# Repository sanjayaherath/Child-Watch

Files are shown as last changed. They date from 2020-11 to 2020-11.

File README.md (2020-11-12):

# Child-Watch

## Introduction ##

This project was developed for EE356-Electronic Product Design and Manufacture Project. A market ready prototype of a child watch was developed.

**Group Members:** [Sanjaya Herath](https://sanjayaherath.github.io/), [Yasiru Ranasinghe](https://www.researchgate.net/profile/Don_Yasiru_Ranasinghe), and [Anupamali Willamuna](https://www.linkedin.com/in/anupamali-willamuna-0743a11a4/?originalSubdomain=lk).

**Supervised by:** [Dr. Janaka Wijayakulasooriya](http://eng.pdn.ac.lk/deee/staff/academic/dr.j.wijayakulasooriya/profile.php), [Dr. Ruwan Ranaweera ](http://eng.pdn.ac.lk/pages/departmentHome/EE/otherpages/staff/rdbranaweera.html), and [Dr. Uditha Navaratne](http://eng.pdn.ac.lk/deee/staff/academic/mr.us.navaratne/profile.php)

## Project Overview ##

The firmware was developed using arduino and PCBs were designed using Eagle CAD. The main components of hardware were arduino pro mini, OLED display, and sim800l.
The child watch includes features such as send and receive a specific number of messages, digital clock, stop watch and recieve notifications through vibrations.

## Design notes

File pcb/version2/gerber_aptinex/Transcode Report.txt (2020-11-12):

   ---- Transcoding 'C:\Users\Ghost\Desktop\project\pcb\version2\gerber_aptinex\version3.GBL' ----   Thu Jan 10 21:57:25 2019

D13   --> D100
-----------------------------------------------------------------

   ---- Transcoding 'C:\Users\Ghost\Desktop\project\pcb\version2\gerber_aptinex\version3.GBS' ----   Thu Jan 10 21:57:25 2019

D11   --> D101
D12   --> D102
D13   --> D103
D14   --> D104
-----------------------------------------------------------------

   ---- Transcoding 'C:\Users\Ghost\Desktop\project\pcb\version2\gerber_aptinex\version3.GTL' ----   Thu Jan 10 22:00:45 2019

D12   --> D105
D13   --> D106
D14   --> D107
D15   --> D108
-----------------------------------------------------------------

   ---- Transcoding 'C:\Users\Ghost\Desktop\project\pcb\version2\gerber_aptinex\version3.GTO' ----   Thu Jan 10 22:01:16 2019

D11   --> D109
D12   --> D110
D13   --> D111
D14   --> D112
D15   --> D113
D16   --> D114
D17   --> D115
-----------------------------------------------------------------

   ---- Transcoding 'C:\Users\Ghost\Desktop\project\pcb\version2\gerber_aptinex\version3.GTP' ----   Thu Jan 10 22:01:19 2019

D11   --> D116
D12   --> D117
D13   --> D118
D14   --> D119
D15   --> D120
D16   --> D121
D17   --> D122
D18   --> D123
-----------------------------------------------------------------

   ---- Transcoding 'C:\Users\Ghost\Desktop\project\pcb\version2\gerber_aptinex\version3.GTS' ----   Thu Jan 10 22:01:19 2019

D11   --> D124
D12   --> D125
D13   --> D126
D14   --> D127
D15   --> D128
D16   --> D129
D17   --> D130
D18   --> D131
D19   --> D132
D20   --> D133
D21   --> D134
D22   --> D135
-----------------------------------------------------------------

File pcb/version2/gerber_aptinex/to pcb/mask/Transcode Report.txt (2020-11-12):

   ---- Transcoding 'C:\Users\Ghost\Desktop\project\pcb\version2\gerber_aptinex\to pcb\mask\version3.GBS' ----   Thu Jan 10 22:14:10 2019

D11   --> D104
D12   --> D105
D13   --> D106
D14   --> D107
-----------------------------------------------------------------

   ---- Transcoding 'C:\Users\Ghost\Desktop\project\pcb\version2\gerber_aptinex\to pcb\mask\version3.GTS' ----   Thu Jan 10 22:14:10 2019

D11   --> D108
D12   --> D109
D13   --> D110
D14   --> D111
D15   --> D112
D16   --> D113
D17   --> D114
D18   --> D115
D19   --> D116
D20   --> D117
D21   --> D118
D22   --> D119
-----------------------------------------------------------------

   ---- Transcoding 'C:\Users\Ghost\Desktop\project\pcb\version2\gerber_aptinex\to pcb\mask\version3.GBS' ----   Fri Jan 11 21:36:22 2019

D13   --> D100
D14   --> D101
-----------------------------------------------------------------

   ---- Transcoding 'C:\Users\Ghost\Desktop\project\pcb\version2\gerber_aptinex\to pcb\mask\version3.GBS' ----   Fri Jan 11 21:36:32 2019

D13   --> D102
D14   --> D103
-----------------------------------------------------------------

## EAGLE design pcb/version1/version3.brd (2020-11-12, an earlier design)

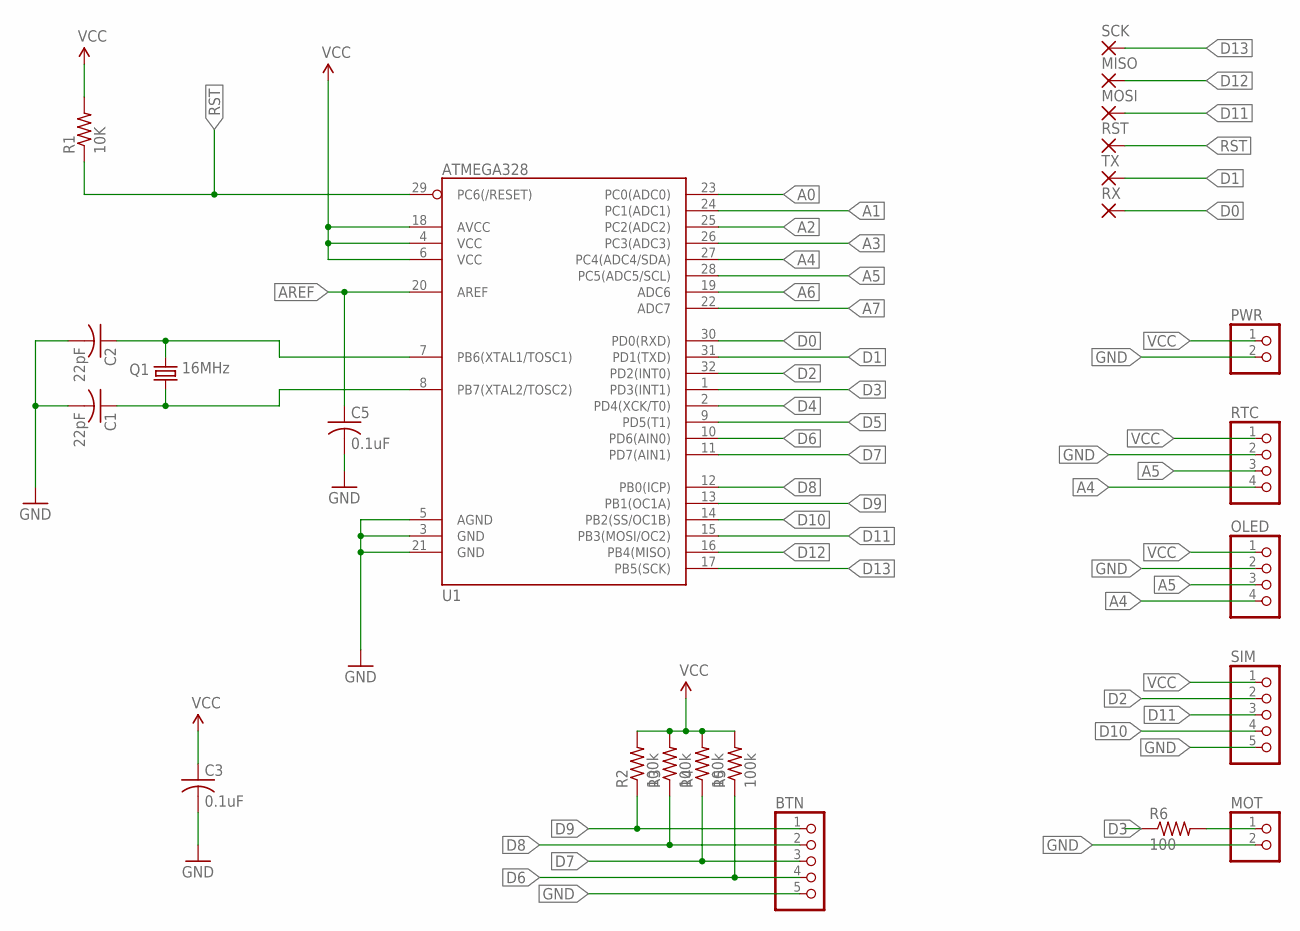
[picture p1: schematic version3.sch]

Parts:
BTN: PINHD-1X5; 1X05
C1, C2: 22pF; C1206
C3, C5: 0.1uF; C0805
MISO: SMD2; SMD1,27-2,54
MOSI: SMD2; SMD1,27-2,54
MOT: PINHD-1X2; 1X02
OLED: PINHD-1X4; 1X04
PWR: PINHD-1X2; 1X02
Q1: 16MHz; TC26V
R1: 10K; R1206
R2, R3, R4, R5: 100k; R1206
R6: 100; R1206
RST: SMD2; SMD1,27-2,54
RTC: PINHD-1X4; 1X04
RX: SMD2; SMD1,27-2,54
SCK: SMD2; SMD1,27-2,54
SIM: PINHD-1X5; 1X05
TX: SMD2; SMD1,27-2,54
U1: ATMEGA328; TQFP32-08

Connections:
A0: U1.23 (PC0(ADC0))
A1: U1.24 (PC1(ADC1))
A2: U1.25 (PC2(ADC2))
A3: U1.26 (PC3(ADC3))
A4: OLED.4, RTC.4, U1.27 (PC4(ADC4/SDA))
A5: OLED.3, RTC.3, U1.28 (PC5(ADC5/SCL))
A6: U1.19 (ADC6)
A7: U1.22 (ADC7)
AREF: C5.1, U1.20 (AREF)
D0: RX.1, U1.30 (PD0(RXD))
D1: TX.1, U1.31 (PD1(TXD))
D2: SIM.2, U1.32 (PD2(INT0))
D3: R6.1, U1.1 (PD3(INT1))
D4: U1.2 (PD4(XCK/T0))
D5: U1.9 (PD5(T1))
D6: BTN.4, R5.1, U1.10 (PD6(AIN0))
D7: BTN.3, R4.1, U1.11 (PD7(AIN1))
D8: BTN.2, R3.1, U1.12 (PB0(ICP))
D9: BTN.1, R2.1, U1.13 (PB1(OC1A))
D10: SIM.4, U1.14 (PB2(SS/OC1B))
D11: MOSI.1, SIM.3, U1.15 (PB3(MOSI/OC2))
D12: MISO.1, U1.16 (PB4(MISO))
D13: SCK.1, U1.17 (PB5(SCK))
GND: BTN.5, C1.2, C2.2, C3.2, C5.2, MOT.2, OLED.2, PWR.2, RTC.2, SIM.5, U1.3 (GND), U1.5 (AGND), U1.21 (GND)
unnamed: MOT.1, R6.2
unnamed: C2.1, Q1.2, U1.7 (PB6(XTAL1/TOSC1))
unnamed: C1.1, Q1.1, U1.8 (PB7(XTAL2/TOSC2))
RST: R1.1, RST.1, U1.29 (PC6(/RESET))
VCC: C3.1, OLED.1, PWR.1, R1.2, R2.2, R3.2, R4.2, R5.2, RTC.1, SIM.1, U1.4 (VCC), U1.6 (VCC), U1.18 (AVCC)

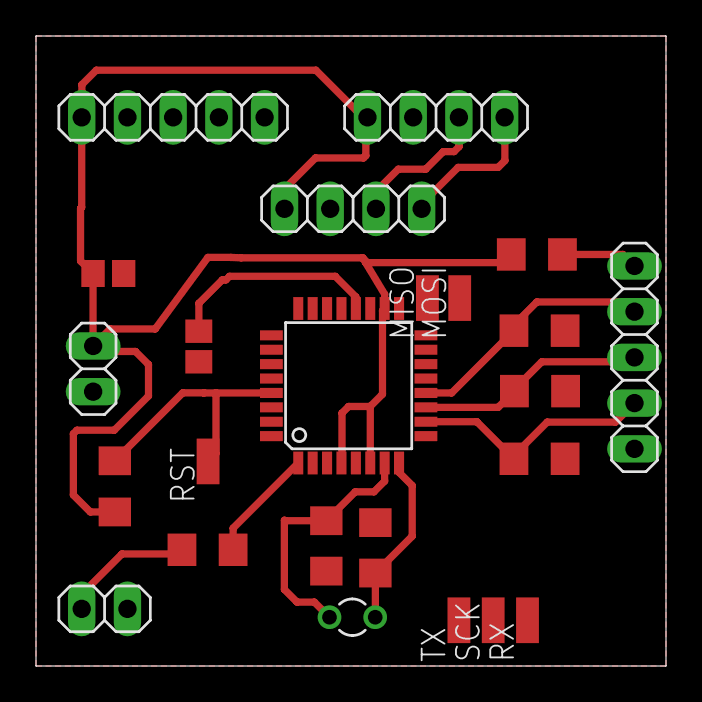
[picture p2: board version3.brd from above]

Board: 2 copper layers, 35.0 x 35.0 mm, 24 parts (0 on the bottom side), 21 nets.

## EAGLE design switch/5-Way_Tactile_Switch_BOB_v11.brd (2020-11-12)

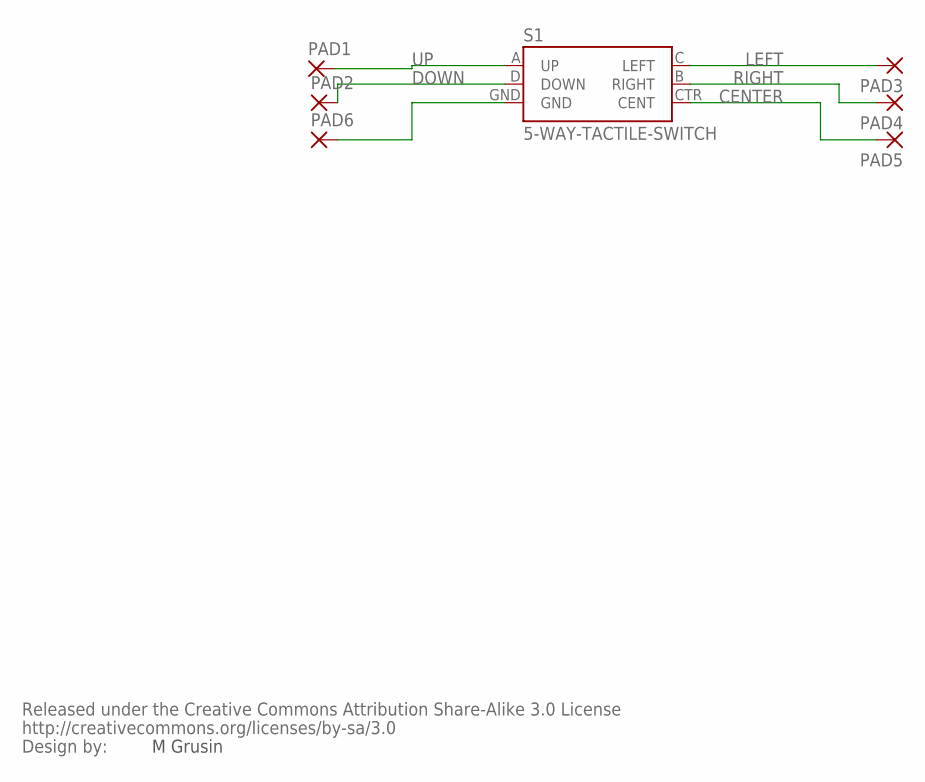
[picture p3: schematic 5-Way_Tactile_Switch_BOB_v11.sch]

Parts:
PAD1, PAD2, PAD3, PAD4, PAD5, PAD6: SMD2; SMD1,27-2,54
S1: 5-WAY-TACTILE-SWITCH; JOYSTICK_MINI
U$2: CREATIVE_COMMONS

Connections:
CENTER: PAD5.1, S1.CTR (CENT)
DOWN: PAD2.1, S1.D (DOWN)
GND: PAD6.1, S1.GND
LEFT: PAD3.1, S1.C (LEFT)
RIGHT: PAD4.1, S1.B (RIGHT)
UP: PAD1.1, S1.A (UP)

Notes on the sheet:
M Grusin

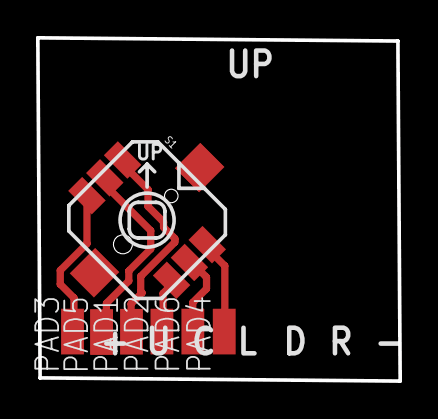
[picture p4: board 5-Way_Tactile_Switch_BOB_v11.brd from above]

Board: 2 copper layers, 20.1 x 19.1 mm, 8 parts (0 on the bottom side), 6 nets.

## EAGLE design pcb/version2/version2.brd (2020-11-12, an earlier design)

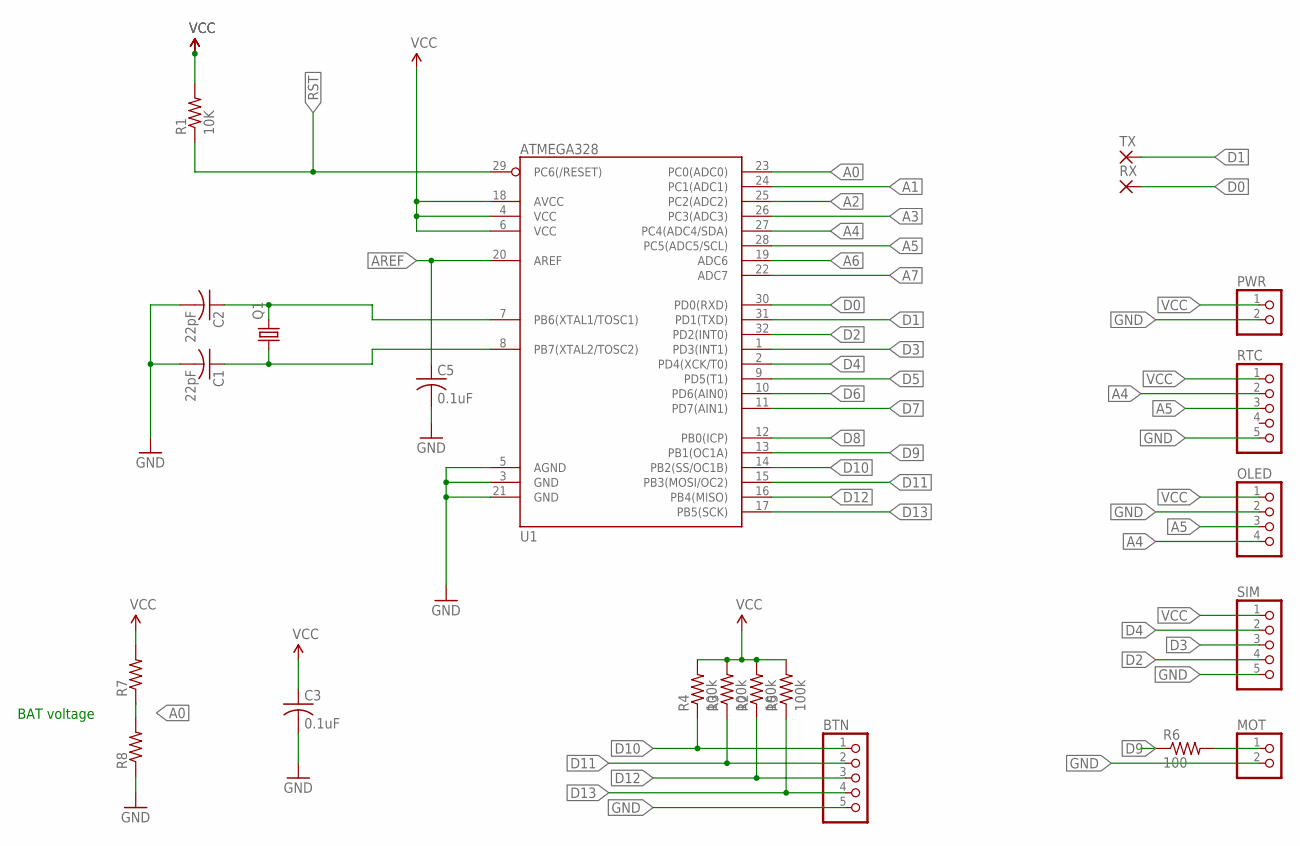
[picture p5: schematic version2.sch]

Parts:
BTN: PINHD-1X5; 1X05
C1, C2: 22pF; C1206
C3, C5: 0.1uF; C0805
MOT: PINHD-1X2; 1X02
OLED: PINHD-1X4; 1X04
PWR: PINHD-1X2; 1X02
Q1: CRYSTALHC18U-V; HC18U-V
R1: 10K; R0805
R2, R3, R4, R5: 100k; R0805
R6: 100; R0805
R7, R8: R-US_R0805; R0805
RTC: PINHD-1X5; 1X05
RX: SMD2; SMD1,27-2,54
SIM: PINHD-1X5; 1X05
TX: SMD2; SMD1,27-2,54
U1: ATMEGA328; TQFP32-08

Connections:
A0: R7.1, R8.2, U1.23 (PC0(ADC0))
A1: U1.24 (PC1(ADC1))
A2: U1.25 (PC2(ADC2))
A3: U1.26 (PC3(ADC3))
A4: OLED.4, RTC.2, U1.27 (PC4(ADC4/SDA))
A5: OLED.3, RTC.3, U1.28 (PC5(ADC5/SCL))
A6: U1.19 (ADC6)
A7: U1.22 (ADC7)
AREF: C5.1, U1.20 (AREF)
D0: RX.1, U1.30 (PD0(RXD))
D1: TX.1, U1.31 (PD1(TXD))
D2: SIM.4, U1.32 (PD2(INT0))
D3: SIM.3, U1.1 (PD3(INT1))
D4: SIM.2, U1.2 (PD4(XCK/T0))
D5: U1.9 (PD5(T1))
D6: U1.10 (PD6(AIN0))
D7: U1.11 (PD7(AIN1))
D8: U1.12 (PB0(ICP))
D9: R6.1, U1.13 (PB1(OC1A))
D10: BTN.1, R4.1, U1.14 (PB2(SS/OC1B))
D11: BTN.2, R3.1, U1.15 (PB3(MOSI/OC2))
D12: BTN.3, R2.1, U1.16 (PB4(MISO))
D13: BTN.4, R5.1, U1.17 (PB5(SCK))
GND: BTN.5, C1.2, C2.2, C3.2, C5.2, MOT.2, OLED.2, PWR.2, R8.1, RTC.5, SIM.5, U1.3 (GND), U1.5 (AGND), U1.21 (GND)
unnamed: MOT.1, R6.2
unnamed: C2.1, Q1.2, U1.7 (PB6(XTAL1/TOSC1))
unnamed: C1.1, Q1.1, U1.8 (PB7(XTAL2/TOSC2))
RST: R1.1, U1.29 (PC6(/RESET))
VCC: C3.1, OLED.1, PWR.1, R1.2, R2.2, R3.2, R4.2, R5.2, R7.2, RTC.1, SIM.1, U1.4 (VCC), U1.6 (VCC), U1.18 (AVCC)

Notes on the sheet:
BAT voltage

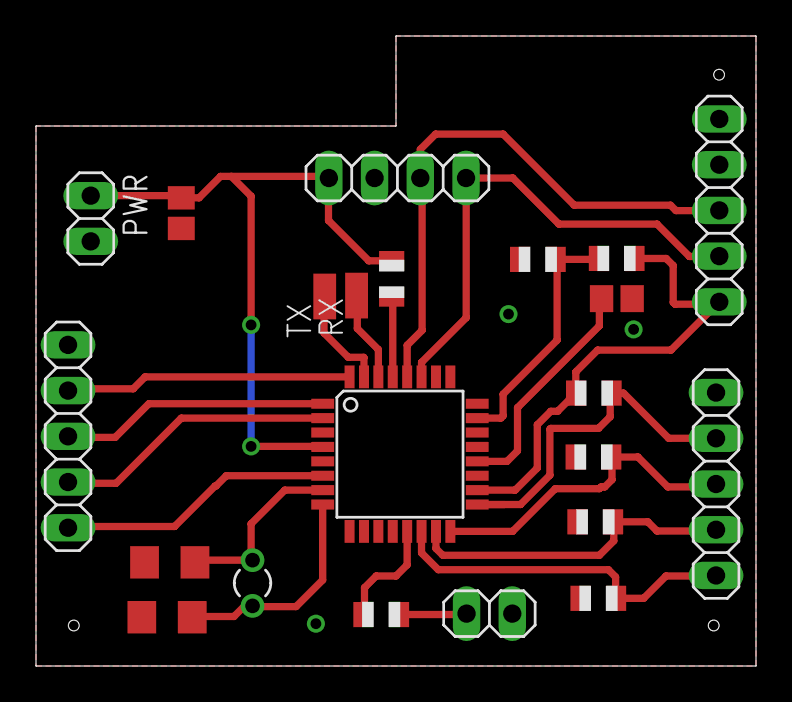
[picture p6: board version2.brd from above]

Board: 2 copper layers, 40.0 x 35.0 mm, 22 parts (0 on the bottom side), 20 nets.

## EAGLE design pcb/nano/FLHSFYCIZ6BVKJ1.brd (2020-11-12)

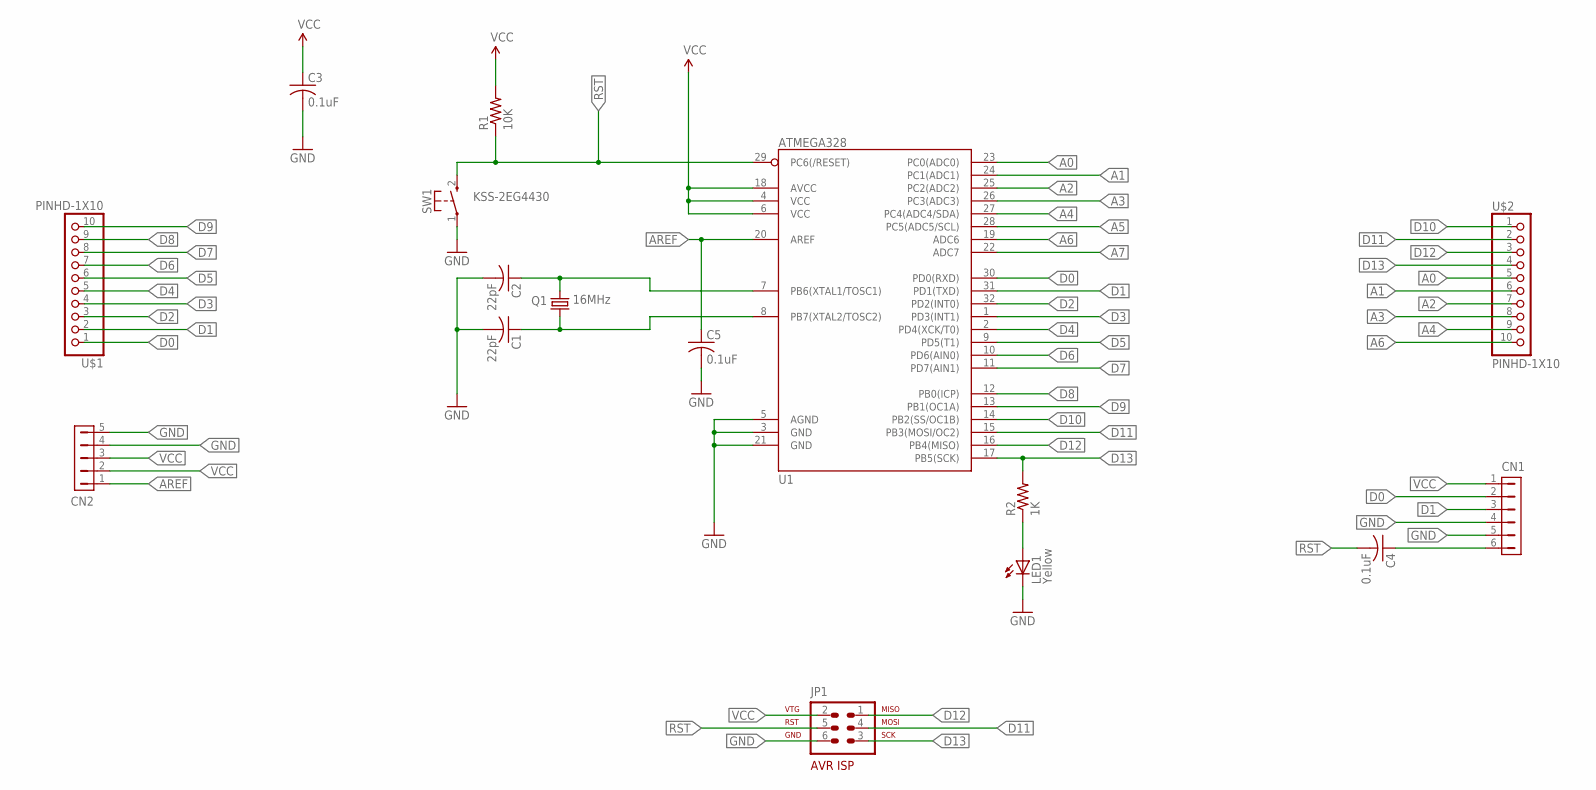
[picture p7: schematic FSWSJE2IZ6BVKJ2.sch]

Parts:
C1, C2: 22pF; C1206
C3, C4, C5: 0.1uF; C0805
CN1: HDR-1X6-SIP-100; SIP-100-6V
CN2: HDR-1X5-SIP-100; SIP-100-5V
JP1: AVR-ISP-6
LED1: Yellow; CHIP-LED0805
Q1: 16MHz; HC49/S
R1: 10K; R1206
R2: 1K; R1206
SW1: KSS-2EG4430
U1: ATMEGA328; TQFP32-08
U$1, U$2: PINHD-1X10; 1X10-BIG

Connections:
A0: U1.23 (PC0(ADC0)), U$2.5
A1: U1.24 (PC1(ADC1)), U$2.6
A2: U1.25 (PC2(ADC2)), U$2.7
A3: U1.26 (PC3(ADC3)), U$2.8
A4: U1.27 (PC4(ADC4/SDA)), U$2.9
A5: U1.28 (PC5(ADC5/SCL))
A6: U1.19 (ADC6), U$2.10
A7: U1.22 (ADC7)
AREF: C5.1, CN2.1, U1.20 (AREF)
D0: CN1.2, U1.30 (PD0(RXD)), U$1.1
D1: CN1.3, U1.31 (PD1(TXD)), U$1.2
D2: U1.32 (PD2(INT0)), U$1.3
D3: U1.1 (PD3(INT1)), U$1.4
D4: U1.2 (PD4(XCK/T0)), U$1.5
D5: U1.9 (PD5(T1)), U$1.6
D6: U1.10 (PD6(AIN0)), U$1.7
D7: U1.11 (PD7(AIN1)), U$1.8
D8: U1.12 (PB0(ICP)), U$1.9
D9: U1.13 (PB1(OC1A)), U$1.10
D10: U1.14 (PB2(SS/OC1B)), U$2.1
D11: JP1.4, U1.15 (PB3(MOSI/OC2)), U$2.2
D12: JP1.1, U1.16 (PB4(MISO)), U$2.3
D13: JP1.3, R2.2, U1.17 (PB5(SCK)), U$2.4
GND: C1.2, C2.2, C3.2, C5.2, CN1.4, CN1.5, CN2.4, CN2.5, JP1.6, LED1.C, SW1.1, U1.3 (GND), U1.5 (AGND), U1.21 (GND)
unnamed: C4.1, CN1.6
unnamed: C2.1, Q1.2, U1.7 (PB6(XTAL1/TOSC1))
unnamed: C1.1, Q1.1, U1.8 (PB7(XTAL2/TOSC2))
unnamed: LED1.A, R2.1
RST: C4.2, JP1.5, R1.1, SW1.2 (S), U1.29 (PC6(/RESET))
VCC: C3.1, CN1.1, CN2.2, CN2.3, JP1.2, R1.2, U1.4 (VCC), U1.6 (VCC), U1.18 (AVCC)

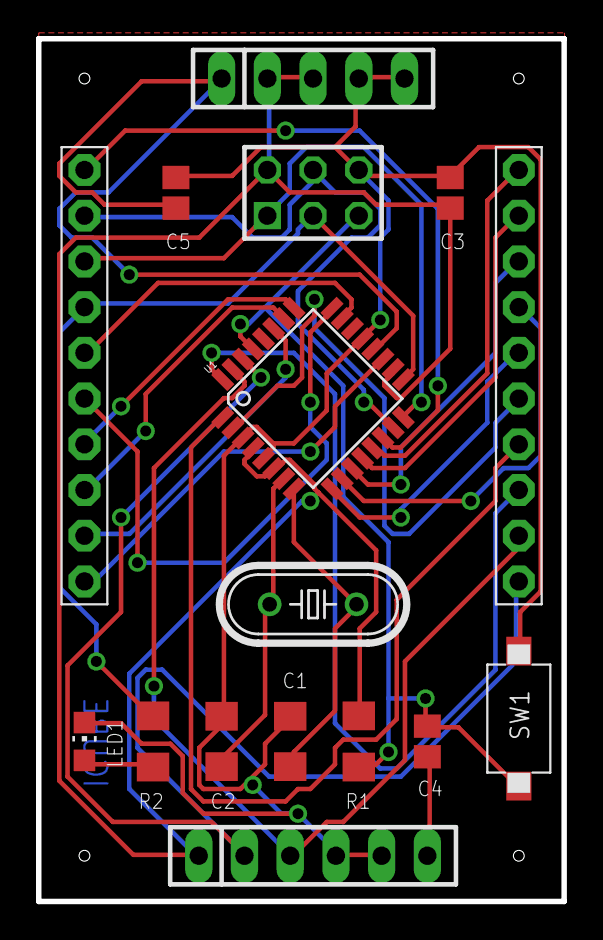
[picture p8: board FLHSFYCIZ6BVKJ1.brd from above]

Board: 2 copper layers, 29.2 x 47.9 mm, 16 parts (0 on the bottom side), 28 nets.

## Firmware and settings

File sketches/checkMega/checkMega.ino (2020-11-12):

#include <Wire.h>
#include <Adafruit_SSD1306.h>
#include "RTClib.h"
#include <Sim800l.h>
#include <SoftwareSerial.h>
#include <EEPROM.h>

RTC_DS3231 rtc;
#define OLED_RESET 4
Adafruit_SSD1306 display(OLED_RESET);

// Variable assignment
char daysOfTheWeek[7][12] = {"SUN", "MON", "TUE", "WED", "THU", "FRI", "SAT"};
char optionKey = 'M', commandKey = '0', preferenceKey;
// Variables for button press
char mode[4] = {'M', 'C', 'P'}, buttonKeyArray [4] = {'8', '5', '2', '4'};
int modeIndex = 0, centerPin = 7, upPin = 9, leftPin = 6, rightPin = 8;
long pressedTime = 0;
// Variables for watch quantities
int hourHand, minuteHand, secondHand;
int preHour, preMinute, preSecond;
int durationOff = 100;
// Variable for stopwatch quantites
int stopHour = 0, stopMinute = 0, stopSecond = 0;
int saveHour = 0, saveMinute = 0, saveSecond = 0, saveMilliSecond = 0;
int startHour, startMinute, startSecond;
int stopMilliSecond = 0, inProgress = 0;
int preStopMilliSecond, preStopSecond, preStopMinute;
int stopMinuteX = 0, stopSecondX = 54, stopMilliSecondX = 108, stopwatchY = 5;
int /*durationSW,*/ initiateStopwatch, loopDelayCount = 20;
// Variable for clock setting
int resetUnit, preChangeUnit = 0, modulusArray[] = {2100, 12, 31, 24, 60};;
// Variables for animation
int lineLength = 0, blackOn = 1;
// Cursor positions
// DateTimeX = {minuteX, hourX, dateX, monthX, yearX}
int DateTimeX[] = {70, 20, 30, 55, 80}, dotX = 56, slashX1 = 45, slashX2 = 70;
// DateTimeY = {timeY, timeY, dateY, dateY, dateY}
int DateTimeY[] = {12, 12, 2, 2, 2}, dotY = 12, slashY = 2;
// Variables for the GSM module
Sim800l Sim800l;  //to declare the library
String numberSms, textSms;
uint8_t index, msgIndex = 1;   // to indicate the message to read.
bool error;       // to store the error output
//bool match;       // to check whether numbers match
String number = "+94719688884";
int motPin = 3, checkSmsDelay = 1, checkSmsTimes = 3;
// Variables for the Pin enter window
int pinArray[4], pinIndex, disableMode = 0;
int pinCursorX[] = {25, 45, 65, 85}, pinCursorY = 12;
// Variables for the Pin/ Contact Info change window
int settingsMode, savedContacts[2][10], EntryX;
int contactCursorX[] = {10, 21, 32, 43, 54, 65, 76, 87, 98, 109}, contactCursorY = 15;
int blinkItCount = 0;
String Number1, Number2;
char contactInfo[13];
//int screenOff = 0;
//unsigned long screenOffTimer;

// Declaring methods
void mainWindowTimeAndDate();
void mainWindowAnime();
void runStopwatch();
void runClockSetting();

void displayColan();
void printHand();
void printDate();
void dotsTicking();
void printDateAndTime();
void drawHoriLine();
void showStopwatch();
void setResetUnitCursor();

void setup()   {

  //Serial.begin(9600);
  display.begin(SSD1306_SWITCHCAPVCC, 0x3C);
  DateTime now = rtc.now();
  printDateAndTime(now.day(), now.month(), daysOfTheWeek[now.dayOfTheWeek()]);

  //gsm
  Sim800l.begin(); // initializate the library.
  //Sim800l.reset();
  pinMode(motPin, OUTPUT);
  index = 1; // first position in the prefered memory storage.
  contactInfo[0] = '+', contactInfo[1] = '9', contactInfo[2] = '4', contactInfo[12] = '\0';
  for (int address = 5; address < 14; address++) {
    contactInfo[address - 2] = EEPROM.read(address) + '0';
  }
  Number1 = (String)(contactInfo);
  for (int address = 15; address < 24; address++) {
    contactInfo[address - 12] = EEPROM.read(address) + '0';
  }
  Number2 = (String)(contactInfo);
}

void loop() {

  //  Serial.println(Number1);
  //  Serial.println(Number2);
  commandKey = '0'; // reset command key to read only once

  DateTime now = rtc.now();
  checkButtonPress(); // Check any buttons are pressed


  // Run main window section
  if (optionKey == 'M') {
    mainWindowTimeAndDate();
    mainWindowAnime();
  }
  // Run setting section
  if (optionKey != 'C')resetUnit = 0;
  if (optionKey == 'C') {
    runClockSetting();
  }

  // Run pin enter section
  if (optionKey == 'P' && disableMode == 0) {
    display.setCursor(pinCursorX[pinIndex], pinCursorY);
    display.print(pinArray[pinIndex]);
    display.display();
    switch (commandKey) {
      case '2':
      case '8':
        changePinValue();
        break;
      case '4' :
        changeIndexOrCheckPin();
        break;
    }
  }

  //gsm


  if (lineLength % 33 == 0 && blackOn == 1) checkSmsDelay++;
  if ((checkSmsDelay % checkSmsTimes) == 0) {
    checkSmsDelay = 1;
    checkSms();
  }


  // Run pin / contact info change section
  if (disableMode == 1) {
    //Serial.println(EntryX);
    displayInfo();
    switch (commandKey) {
      case '4':
        increaseEntryX();
        break;
      case '2':
      case '8':
        changeEntryValue();
        break;
    }
  }
}

/////////////////////////////////////// MAIN METHODS /////////////////////////////////////////////
// Check for the pressed button
void checkButtonPress() {
  // Check for the pressed button
  for (int pinVal = 6; pinVal < 10; pinVal++) {
    if (digitalRead(pinVal) == LOW && (millis() - pressedTime) > 150) {
      // Get the corresponding keypad button
      pressedTime = millis();
      commandKey = buttonKeyArray[pinVal - 6];
      if (commandKey == '5' && disableMode == 0) modeIndex = (++modeIndex) % 3;
      if (disableMode == 1 && commandKey == '5') {
        settingsMode = (++settingsMode) % 4;
        display.clearDisplay(); EntryX = 0;
      }
    }
  }

/*
  if (commandKey != '0' && screenOff == 0) {
    screenOffTimer = millis();
  }

  if (millis() - screenOffTimer > 60000 && screenOff != 1) {
    display.clearDisplay();
    display.display();
    screenOff = 1;
  }
  else if(commandKey != '0' && screenOff == 1 ){ 
    screenOff = 0;    
    screenOffTimer = millis();
    modeIndex = 0;
    optionKey = 'C';
 }
*/
  preferenceKey = mode[modeIndex];
  // Current window is the main window
  if (preferenceKey == 'M' && optionKey != 'M') {
    //durationSW = 52;
    optionKey = 'M';
    DateTime now = rtc.now();
    printDateAndTime(now.day(), now.month(), daysOfTheWeek[now.dayOfTheWeek()]);
    lineLength = 0; blackOn = 1;
  }
  // Current window is the settings window
  if (preferenceKey == 'C' && optionKey != 'C') {
    display.clearDisplay();
    //durationSW = 50;
    optionKey = 'C';
  }
  // Current window is the enter pin window
  if (preferenceKey == 'P' && optionKey != 'P') {
    //durationSW = 50;
    optionKey = 'P';
    displayEnterPin();
    pinIndex = 0;
    for (int index = 0; index < 4; index++) {
      pinArray[index] = 0;
    }
  }
}

// Main window of the clock
void mainWindowTimeAndDate() {
//  if(screenOff == 1) return;
  displayColan(':');
  display.display();
  DateTime now = rtc.now();
  preSecond = secondHand;
  secondHand = now.second();
  if (secondHand == 0) {
    preMinute = minuteHand;
    minuteHand = now.minute();
    // Display the change in minutes
    printHand(preMinute, minuteHand, DateTimeX[0], DateTimeY[0], 2);

    // Trigger hour change
    if (preMinute > minuteHand) {
      preHour = hourHand;
      hourHand = now.hour();
      // Display the change in hours
      printHand(preHour, hourHand, DateTimeX[1], DateTimeY[1], 2);

      // Trigger date change
      if (preHour > hourHand) {
        printDateAndTime(now.day(), now.month(), daysOfTheWeek[now.dayOfTheWeek()]);
      }
    }
  }
  if (preSecond != secondHand) {
    display.setCursor(dotX, dotY);
    display.setTextColor(BLACK);
    displayColan(':');
    display.display();
    delay(durationOff);
    display.setTextColor(WHITE);
  }
}

// Main window animation
void mainWindowAnime() {
  //  if (commandKey == '4') sendMessage();
  if (preSecond == secondHand) delay(durationOff);
  lineLength = lineLength % 33;
  if (lineLength == 0 && blackOn == 1)blackOn = 0;
  else if (lineLength == 0)blackOn = 1;
//  lineLength++;
//  if(screenOff == 1) return;
  drawHoriLine(lineLength++);
}

// Run clock setting window
void runClockSetting() {
  if (commandKey == '4') {
    resetUnit = ++resetUnit % 5;
  }
  setResetUnitCursor();
}

/////////////////////////////////////SUBORDINATE METHODS////////////////////////////////
// Print time quantites
void printHand(int preUnit, int timeUnit, int cursorX, int cursorY, int numDigit) {
  display.setCursor(cursorX, cursorY);
  display.setTextColor(BLACK);
  if (preUnit < 10 && numDigit == 2)display.print(0);
  display.print(preUnit);
  display.setCursor(cursorX, cursorY);
  display.setTextColor(WHITE);
  if (timeUnit < 10 && numDigit == 2)display.print(0);
  display.print(timeUnit);
}
// Print date quantites
void printDate(int timeUnit, int cursorX, int cursorY) {
  display.setCursor(cursorX, cursorY);
  display.setTextColor(WHITE);
  display.setTextSize(1);
  display.print(timeUnit);
  display.setTextSize(3);
}
//Display date/month DAY
void printDateAndTime(int dayInfo, int monthInfo, String dayName) {
  display.clearDisplay();
  display.setCursor(DateTimeX[2], DateTimeY[2]);
  display.setTextColor(WHITE);
  display.setTextSize(1);
  display.print(dayInfo);
  display.print(" / ");
  display.print(monthInfo);
  display.print("  ");
  display.print(dayName);
  display.setTextSize(3);
  DateTime now = rtc.now();
  hourHand = now.hour(); minuteHand = now.minute(); secondHand = now.second();
  printHand(0, hourHand, DateTimeX[1], DateTimeY[1], 2);
  printHand(0, minuteHand, DateTimeX[0], DateTimeY[0], 2);
}
// Display the animation
void drawHoriLine(int lineWidth) {
  int cursorX = 0;
  double width = (double)lineWidth ;
  width++;
  width = ceil((width / 8) * (width / 6));
  while (cursorX < width) {
    if (blackOn == 0) {
      display.drawPixel(cursorX, 31 - lineWidth, WHITE);
      display.drawPixel(127 - cursorX++, 31 - lineWidth, WHITE);
    }
    else {
      display.drawPixel(cursorX, 31 - lineWidth, BLACK);
      display.drawPixel(127 - cursorX++, 31 - lineWidth, BLACK);
    }
  }
//  if(screenOff == 1) display.clearDisplay();
}

// Set stopwatch screen and display
void showStopwatch() {
  display.setTextColor(WHITE);
  display.setTextSize(3);
  display.clearDisplay();
  // Display the minute in stopwatch
  printHand(0, preStopMinute, stopMinuteX, stopwatchY, 2);
  display.print(":");
  // Display the second in stopwatch
  printHand(0, preStopSecond, stopSecondX, stopwatchY, 2);
  display.print(":");
  // Display the milliscond in stopwatch
  printHand(0, preStopMilliSecond, stopMilliSecondX, stopwatchY, 1);
  display.display();
}

// Change clock settings
void setResetUnitCursor() {
  DateTime now = rtc.now();
  int currentSettings[] = {(int)now.year(), now.month(), now.day(), now.hour(), now.minute()};
  int changeIndex = 4 - resetUnit, changeUnit = currentSettings[changeIndex];
  int timeBound = modulusArray[changeIndex];
  if (preChangeUnit != changeUnit) {
    display.clearDisplay();
    preChangeUnit = changeUnit;
  }
  display.setTextSize(3); display.setTextColor(WHITE);
  displayColan(':'); displayColan('/'); display.display();

  if (resetUnit < 2) printHand(0, changeUnit, DateTimeX[resetUnit], DateTimeY[resetUnit], 2);
  else printDate(changeUnit, DateTimeX[resetUnit], DateTimeY[resetUnit]);
  display.display();
  if (commandKey == '2' || commandKey == '8') {
    changeUnit = changeUnit + (commandKey == '2') - (commandKey == '8');
    changeUnit = (timeBound + (changeUnit % timeBound)) % timeBound;
    switch (changeIndex) {
      case 0:
      case 1:
      case 2:
        changeUnit = timeBound * (changeUnit == 0) + changeUnit;
        break;
    }
    currentSettings[changeIndex] = changeUnit;
    rtc.adjust(DateTime(currentSettings[0], currentSettings[1], currentSettings[2], currentSettings[3], currentSettings[4], 0));
  }

  // Save parameters for the stopwatch
  if (commandKey == '2' || commandKey == '8') {
    saveHour = stopHour, saveMinute = preStopMinute, saveSecond = preStopSecond;
    saveMilliSecond = preStopMilliSecond;
    initiateStopwatch = 0;
  }
}
// Display colans
void displayColan(char sign) {
  switch (sign) {
    case ':':
      display.setCursor(dotX, dotY);
      display.print(':');
      break;
    case '/':
      display.setTextSize(1);
      display.setCursor(slashX1, slashY);
      display.print('/');
      display.setCursor(slashX2, slashY);
      display.print('/');
      display.setTextSize(3);
      break;
  }
}
// Display 'Enter Pin'
void displayEnterPin() {
  display.clearDisplay();
  display.setTextSize(1);
  display.setCursor(DateTimeX[2] - 6, DateTimeY[2]);
  display.print("**Enter Pin**");
  display.setTextSize(3);
}
// Entering the pin
void changePinValue() {
  int pinValue = pinArray[pinIndex];
  pinValue = pinValue + (commandKey == '2') - (commandKey == '8');
  pinArray[pinIndex] = (10 + pinValue) % 10;
  displayEnterPin();
}
// Change the digit of the 4-digit Pin and check for permission
void changeIndexOrCheckPin() {
  int misMatch = 0;
  if (++pinIndex > 3) {
    for (int address = 0; address < 4; address++) {
      if (EEPROM.read(address) != pinArray[address]) {
        optionKey = 'M';
        misMatch = 1;
      }
    }
    if (misMatch == 0) {
      disableMode = 1;
      display.clearDisplay();
      settingsMode = 0, EntryX = 0, commandKey = '0';
      loadValues();
    }
  }
  else {
    displayEnterPin();
  }
}
// Load values from the EEPROM to the program
void loadValues() {
  // Storing the contact information
  for (int infoRow = 0; infoRow < 2; infoRow++) {
    for (int infoCol = 0; infoCol < 10; infoCol++) {
      int address = 10 * (infoRow) + infoCol + 4;
      savedContacts[infoRow][infoCol] = EEPROM.read(address);
    }
  }
}
// Display information in settings window
void displayInfo() {
  switch (settingsMode) {
    case 0: // Display the pin number
      display.setTextSize(1);
      display.setCursor(DateTimeX[2] - 12, DateTimeY[2]);
      display.print("*Enter New Pin*");
      display.setTextSize(3);
      for (int index = 0; index < 4; index ++) {
        display.setCursor(pinCursorX[index], pinCursorY);
        display.print(pinArray[index]);
      }
      display.display();
      blinkItCount = (++blinkItCount) % 20;
      if (blinkItCount == 0)blinkIt(pinArray[EntryX], pinCursorX[EntryX], pinCursorY);
      break;
    case 1: // Display the contact info 1
      display.setTextSize(1);
      display.setCursor(DateTimeX[2] + 6, DateTimeY[2]);
      display.print("Contact 1");
      display.setTextSize(2);
      for (int index = 0; index < 10; index ++) {
        display.setCursor(contactCursorX[index], contactCursorY);
        display.print(savedContacts[0][index]);
      }
      display.display();
      blinkItCount = (++blinkItCount) % 20;
      if (blinkItCount == 0)blinkIt(savedContacts[0][EntryX], contactCursorX[EntryX], contactCursorY);
      display.setTextSize(3);
      break;
    case 2: // Display the contact info 2
      display.setTextSize(1);
      display.setCursor(DateTimeX[2] + 6, DateTimeY[2]);
      display.print("Contact 2");
      display.setTextSize(2);
      for (int index = 0; index < 10; index ++) {
        display.setCursor(contactCursorX[index], contactCursorY);
        display.print(savedContacts[1][index]);
      }
      display.display();
      blinkItCount = (++blinkItCount) % 20;
      if (blinkItCount == 0)blinkIt(savedContacts[1][EntryX], contactCursorX[EntryX], contactCursorY);
      display.setTextSize(3);
      break;
    case 3: // Display the save settings window
      display.setTextSize(1);
      display.setCursor(DateTimeX[2] - 6, DateTimeY[2]);
      display.print("Save settings?");
      //display.setCursor(DateTimeX[2] - 10, DateTimeY[2] + 14);
      display.setCursor(0, DateTimeY[2] + 10);
      display.print("Move, Forward to save");
      //display.setCursor(DateTimeX[2] - 10, DateTimeY[2] + 24);
      display.setCursor(10, DateTimeY[2] + 20);
      display.print("Backward to cancel");
      display.display();
      break;
  }
}
// Blink the current variable digit
void blinkIt(int value, int cursorX, int cursorY) {
  display.setCursor(cursorX, cursorY);
  display.setTextColor(BLACK);
  display.print(value);
  display.display();
  delay(100);
  display.setTextColor(WHITE);
}
// Change the value of the current variable digit
void changeEntryValue() {
  switch (settingsMode) {
    case 0:
      pinArray[EntryX] = pinArray[EntryX] + (commandKey == '2') - (commandKey == '8');
      pinArray[EntryX] = (10 + pinArray[EntryX] % 10) % 10;
      display.clearDisplay();
      break;
    case 1:
      savedContacts[0][EntryX] = savedContacts[0][EntryX] + (commandKey == '2') - (commandKey == '8');
      savedContacts[0][EntryX] = (10 + savedContacts[0][EntryX] % 10) % 10;
      display.clearDisplay();
      break;
    case 2:
      savedContacts[1][EntryX] = savedContacts[1][EntryX] + (commandKey == '2') - (commandKey == '8');
      savedContacts[1][EntryX] = (10 + savedContacts[1][EntryX] % 10) % 10;
      display.clearDisplay();
      break;
    case 3:
      switch (commandKey) {
        case '2':
          // Save the new pin and return to main window
          for (int addressI = 0; addressI < 2; addressI++ ) {
            for (int addressJ = 0; addressJ < 10; addressJ++ ) {
              int address = 10 * addressI + addressJ + 4;
              EEPROM.write(address, savedContacts[addressI][addressJ]);
              if (address > 4 && address < 14) {
                contactInfo[address - 2] = savedContacts[addressI][addressJ] + '0';
                if (address == 13) {
                  //contactInfo[12] = '\0';
                  Number1 = (String)(contactInfo);
                }
              }
              else if (address > 14 && address < 24) {
                contactInfo[address - 12] = savedContacts[addressI][addressJ] + '0';
                if (address == 23) {
                  //contactInfo[12] = '\0';
                  Number2 = (String)(contactInfo);
                }
              }
            }
          }
          for (int address; address < 4; address++) {
            EEPROM.write(address, pinArray[address]);
          }
          for (int index = 0; index < 4; index++) {
            pinArray[index] = 0;
          }
          disableMode = 0;
          display.clearDisplay();
          display.setCursor(30, 10);
          display.setTextSize(2);
          display.print("Saved!");
          display.display();
          delay(1000);
          modeIndex = (++modeIndex) % 3;
          break;
        case '8':
          // Discard changes and return to main window
          disableMode = 0;
          display.clearDisplay();
          display.display();
          modeIndex = (++modeIndex) % 3;
          break;
      }
  }
}
// Change the index of the variable digit
void increaseEntryX() {
  switch (settingsMode) {
    case 0:
      EntryX = (++EntryX) % 4;
      break;
    case 1:
    case 2:
      EntryX = (++EntryX) % 10;
      break;
  }
}

// GSM METHODS //////////////////////////////

void checkSms() {
  delay(100);
  numberSms = Sim800l.getNumberSms(msgIndex);
  delay(100);
  Serial.print(numberSms + "\t");
  Serial.println(msgIndex);
  delay(1000);

  if (numberSms.equals(Number2) || numberSms.equals(Number2)) {
    // Serial.println("match");
    displayMesRec();
    playSmsAlarm();
    delay(5000);
    //sendMessage();
  }

  if (numberSms.length() > 10) {
    msgIndex++;
  }
  if (msgIndex > 1) {
    msgIndex = 1;
    Sim800l.delAllSms();
  }
}

void displayMesRec() {
  display.clearDisplay();
  display.setCursor(20, 15);
  display.setTextSize(1);
  display.print("Message Received");
  display.display();
  display.setTextSize(3);
  display.clearDisplay();
  DateTime now = rtc.now();
  printDateAndTime(now.day(), now.month(), daysOfTheWeek[now.dayOfTheWeek()]);
}

void sendMessage() {          // send sms to contacts
  char* sendsmstext = "match";
  error = Sim800l.sendSms(number, sendsmstext);
  if (error) {
    digitalWrite(motPin, HIGH);
    delay(800);
    digitalWrite(motPin, LOW);
  }


}

void playSmsAlarm() {         //sms received notification motor
  for (int i = 0; i < 5; i++) {
    digitalWrite(motPin, HIGH);
    delay(400);
    digitalWrite(motPin, LOW);
    delay(200);
    digitalWrite(motPin, HIGH);
    delay(400);
    digitalWrite(motPin, LOW);
    delay(1000);
  }
}

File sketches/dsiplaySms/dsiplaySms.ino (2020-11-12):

//#include <SPI.h>
#include <Wire.h>
//#include <Adafruit_GFX.h>
#include <Adafruit_SSD1306.h>
#include "RTClib.h"
#include <Sim800l.h>
#include <SoftwareSerial.h> //is necesary for the library!! 
#include "U8glib.h"

RTC_DS3231 rtc;
#define OLED_RESET 4
Adafruit_SSD1306 display(OLED_RESET);

// Variable assignment
char daysOfTheWeek[7][12] = {"SUN", "MON", "TUE", "WED", "THU", "FRI", "SAT"};
char optionKey = 'M', commandKey = '0';
char preferenceKey;
// Variables for button press
char mode[5] = {'M', 'S', 'C', 'P'};
int modeIndex = 0, centerPin = 7, upPin = 9, leftPin = 6, rightPin = 8;
long pressedTime = 0;
// Variables for time quantities 
int hourHand, minuteHand, secondHand;
int preHour, preMinute, preSecond;
// Variable for stopwatch quantites
int stopMinute = 0, stopSecond = 0, stopMilliSecond = 0, inProgress = 0, preUnit, resetSW = 0;
int stopMinuteX = 0, stopSecondX = 54, stopMilliSecondX = 108, stopwatchY = 5;
int durationSW, resetUnit, loopDelayCount = 20;
// Variables for animation
int lineLength = 0, blackOn = 1;
// Cursor positions
int hourX = 20, minuteX = 70, dotX = 54, timeY = 12;
int dateX = 30, dateY = 2,durationOff;
//gsm
Sim800l Sim800l;  //to declare the library
String numberSms;
uint8_t index;   // to indicate the message to read.
bool error;       // to store the error output
bool match;       // to check whether numbers match
String number ="+94719688884";
int LEDpin=5, checkSmsDelay = 1, checkSmsTimes = 10;

// Declaring methods
void mainWindowTimeAndDate();
void mainWindowAnime();
void runStopwatch();
void runClockSetting();

void displayColan();
void printHand();
void dotsTicking();
void printDateAndTime();
void drawHoriLine();
void reserStopwatch();
void setResetUnitCursor();

void setup()   {               
  Serial.begin(9600);
 // rtc.adjust(DateTime(2018, 11, 8, 10, 53, 00));
  // by default, we'll generate the high voltage from the 3.3v line internally! (neat!)
  display.begin(SSD1306_SWITCHCAPVCC, 0x3C);  // initialize with the I2C addr 0x3C (for the 128x32)
  DateTime now = rtc.now();
  printDateAndTime(now.day(),now.month(),daysOfTheWeek[now.dayOfTheWeek()]);
//gsm
  
  Sim800l.begin(); // initializate the library. 
  index=1; // first position in the prefered memory storage. 
  
}
int times = 0;
void loop(){
  // Set duration for pulsating 
  if(inProgress == 0)durationOff = 80;
  if(inProgress == 1)durationOff = 10;
  commandKey = '0';
  
  DateTime now = rtc.now();
  // Check button press
    checkButtonPress();
  /* 
  // Read from the serial 
  if(Serial.available()){
    preferenceKey = (char)Serial.read();
    while(Serial.available()){
    Serial.read();
    }
    commandKey = preferenceKey;
  }
  // Serial read is over
  */  
  // Run main window section
  //if(checkSms == 0 && optionKey == 'M') Serial.println("SHAPE");
  if(optionKey == 'M'){  
    mainWindowTimeAndDate();
    mainWindowAnime();
  }
  // Run stopwatch section
  if(optionKey == 'S' || inProgress == 1){
    runStopwatch();
    }
  // Run setting section  
  if(optionKey != 'C')resetUnit = 0;
  if(optionKey == 'C'){    
     runClockSetting();
    }  
  // Run pin enter section
//  if()
  
 //gsm 
  if(lineLength%33 == 0 && blackOn == 1) checkSmsDelay++;
  if ((checkSmsDelay % checkSmsTimes) == 0){
    checkSmsDelay = 1;
  getNumber();
  checkMatch(numberSms);
 bool error=Sim800l.delAllSms();
  }
} 

/////////////////////////////////////// MAIN METHODS ///////////////////////////////////////////// 
// Main window of the clock
void mainWindowTimeAndDate(){
    displayColan(':');
    display.display();
    DateTime now = rtc.now();
    preSecond = secondHand;
    secondHand = now.second();
      if (secondHand == 0){   
        preMinute = minuteHand;
        minuteHand = now.minute();      
        // Display the change in minutes
        printHand(preMinute,minuteHand,minuteX,timeY,2);
      
        // Trigger hour change       
          if (preMinute > minuteHand){          
            preHour = hourHand;
            hourHand = now.hour();          
            // Display the change in hours
            printHand(preHour,hourHand,hourX,timeY,2);
          
            // Trigger date change          
              if (preHour > hourHand){                    
                printDateAndTime(now.day(),now.month(),daysOfTheWeek[now.dayOfTheWeek()]);                                       
                }                               
              }        
            }
    if (preSecond != secondHand){
    display.setCursor(dotX,timeY);
    display.setTextColor(BLACK);
    displayColan(':');
    display.display();    
    delay(durationOff);
    display.setTextColor(WHITE);                       
        }
 }
      
// Main window animation
void mainWindowAnime(){
  if(preSecond == secondHand) delay(durationOff);
  lineLength = lineLength % 33;
  if(lineLength == 0 && blackOn == 1)blackOn = 0;
  else if (lineLength == 0)blackOn = 1;
  drawHoriLine(lineLength++); 
  }

// Stopwatch window
void runStopwatch(){
  if(stopMinute == 0 && stopSecond == 0 && stopMilliSecond == 0 && resetSW == 0){
    stopMinute = 0, stopSecond = 0, stopMilliSecond = 0;
    resetStopwatch();  
    }
  // Start the stopwatch
  if (commandKey == '2' || inProgress == 1){
  inProgress = 1;
  delay(durationSW);
  if(stopMilliSecond == 10 ){
    stopMilliSecond = stopMilliSecond % 10;  
    preUnit = stopSecond++;
    //
    if(optionKey == 'S')printHand(preUnit,stopSecond%60,stopSecondX,stopwatchY,2);
    if(stopSecond == 60){
      stopSecond = stopSecond % 60; 
      preUnit = stopMinute++;
      //
      if(optionKey == 'S')printHand(preUnit,stopMinute%100,stopMinuteX,stopwatchY,2);
      }
      stopMinute = stopMinute % 100;
    }     
  preUnit = stopMilliSecond++;
  // 
  if(optionKey == 'S')printHand(preUnit,stopMilliSecond%10,stopMilliSecondX,stopwatchY,1);
  display.display();
 }

// Pause the operation
  if(commandKey == '8' && optionKey == 'S'){
    if(inProgress == 0){
      stopMinute = 0, stopSecond = 0, stopMilliSecond = 0;
      resetStopwatch();
    }
    // Reset the stopwatch
    else inProgress = 0;      
      }   
   
  }

// Run clock setting window
void runClockSetting(){
  // preHour = hourHand; preMinute = minuteHand;
      switch (commandKey){
        case '4':
          resetUnit++;
          resetUnit = (2 + resetUnit % 2) % 2;
          break;
        case '6':
          resetUnit--;
          resetUnit = (2 + resetUnit % 2) % 2;
          break;
        }
    setResetUnitCursor();
  }
/////////////////////////////////////SUBORDINATE METHODS////////////////////////////////
// Display colans
void displayColan(char sign){
  switch (sign){
    case ':':
      display.setCursor(dotX,timeY);
      display.print(':');
      break;
    case '/':
      break;
    }
  }
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

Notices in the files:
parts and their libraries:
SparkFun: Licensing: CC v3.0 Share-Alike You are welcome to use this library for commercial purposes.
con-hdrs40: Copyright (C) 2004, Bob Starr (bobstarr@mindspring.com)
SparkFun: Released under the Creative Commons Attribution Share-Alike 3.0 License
